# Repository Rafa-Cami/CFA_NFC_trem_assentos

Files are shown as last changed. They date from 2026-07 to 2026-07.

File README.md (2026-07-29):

<p align="center">
  <br/>
  <b>Prioriza: Sistema de sensores para assentos preferenciais</b><br/>
  <text>🚈 Relatório do projeto</text>
</p>

<br/>

## 📍Introdução

O projeto de cartões de identificação, desenvolvido na disciplina de [CFA](https://github.com/FNakano/CFA), tem como objetivo desenvolver um projeto utilizando a tecnologia de NFC para realizar avisos sonoros e alertar os passageiros do vagão. Para ver outros projetos relacionados que utilizam NFC, utilizamos como inspiração o projeto [CardForRPG](https://github.com/Felipe256/CardForRPG) e o projeto [SMAC - Sistema de Monitoramento para Assentos de Cadeira de Roda](https://github.com/Anemaygi/SMAC/tree/master/projeto) que apresenta uma possibilidade de implementação para os sensores de toque detectarem presença em um assento.

### 🗺️ Aplicação Real

A iniciativa foi inspirada no sistema de sensores utilizado no metrô da Coreia do Sul e seu aplicativo [pinklight](https://play.google.com/store/apps/details?id=kr.doweb.pinklight&hl=pt_BR), para criar uma solução baseada em IoT que incentive os passageiros a dar lugar à mulheres grávidas no assento preferencial. Segundo o [estudo de caso](https://publicadministration.un.org/unpsa/en/Home/Case-Details-Public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), "Recentemente, como muitos passageiros ficam absortos em seus smartphones enquanto viajam de ônibus ou metrô, é possível que raramente notem uma gestante por perto. Partindo do princípio de que muitos dos passageiros que não estão grávidos, mas ocupam assentos preferenciais, estariam de fato dispostos a ceder o lugar a uma mulher caso percebessem que ela está grávida, a cidade de Busan lançou o 'Pink Light'".

Assim, o dispositivo seria uma forma de alertar os passageiros quando devem ceder seu lugar para outro passageiro, sem necessidade de perguntar e sem que seja necessário pedir. É uma tecnologia relativamente barata de ser implementada como política pública que incentiva o bem-estar de diferentes grupos sociais com direito ao assento preferencial, como por exemplo: Pessoas com deficiência, pessoas com crianças de colo, idosos, obesos, gestantes, pessoas com restrição de mobilidade e autistas.

## 🗂️ Organização do repositório e primeiros passos:

## 👩‍🦯‍➡️ História de usuário (exemplificação de como funcionaria o projeto):

### usuário com direito ao assento preferencial

 1. ao entrar no trem o usuario deve ter em mãos o acessorio (cartão ou chaveiro) que tem informações sobre o assento preferencial
 2. o usuário deve encostar o acessório no dispositivo no sensor de nfc (requisito esse estar localizado com fácil acesso)
 3. o usuário verá a luz acima dos assentos liberados acender
     3.5 Se não houverem assentos livres, os passageiros ouviram o anuncio da chegada do passageiro preferencial e necessidade de liberação de assentos preferenciais
 4. o usuário pode ir até o assento, necessitando possivelmente que outros passageiros deem lugar sabendo da presença do passageiro preferencial

### usuários sem acesso ao assento preferencial

 1. ao chegar no trem, se houver um assento vazio e nao houver pessoas preferenciais usuário pode se sentar no assento preferencial
 2. o usuário fica tranquilo e quando chega na proxima estação se houver um usuario que deseja usar o assento preferencial ele ouve um anúncio
 3. o usuario deve se levantar, permitindo que a luz de assento livre ligue
 4. o usuario com direito ao assento verá o assento livre e se sentará nele

### preocupação com funcionalidade

- importante reforçar que a implementação do projeto envolve também a mudança no comportamento do usuário. Se implementado na vida real, o sucesso do projeto depende das pessoas cederem seus assentos. 

- O projeto em suas primeiras versões tem impedimentos para seu funcionamento em horários de pico. Os motivos são 
1. limitação no número de assentos
2. Possível lotação pode impedir o usuário de chegar ate o sensor do cartão. A lotação tambem pode impedir o usuário de enxergar a luz que sinaliza o assento livre, bem como impedir o deslocamento do usuario até lá.

## ⚙️ Como foi feito o projeto:

### 🔧 Componentes:
O projeto utiliza:
- 3 ESP32-C3 mini
- 1 PN532
- 1 Buzzer
- 4 Módulo sensor de toque capacitivo TTP223B
- 2 LED
- 2 Protoboard
- N Jumper
- PC ou outro dispositivo para atuar como servidor

**código em micropython e comunicação via TCP/IP com necessidade de os ESP32 e o Servidor se conectarem em mesma rede**

## 📖 Documentação do Código:

### Estrutura do Projeto:
O projeto está organizado em três blocos principais, cada um com uma função bem definida no funcionamento do sistema:

- Módulo de leitura NFC: localizado em 'esp_comunicando.py' e 'nfc_buzzer.py'. Esse módulo é responsável por interagir com o leitor PN532, ler o UID de cartões ou chaveiros NFC e identificar se o identificador corresponde a um usuário autorizado, além da comunicação com o servidor. Também há uma camada de inicialização em 'start.py', que chama o fluxo principal do leitor.

<p align="center">
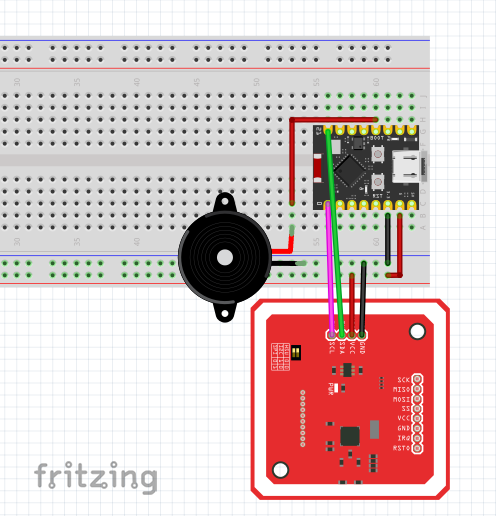
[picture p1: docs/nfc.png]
  <br/>
  <b>Esquema do Módulo de Leitor NFC</b><br/>
</p>

- Módulo de assentos: implementado em 'sensor_v1.py' e 'seat_state.py'. Aqui ficam os sensores de toque capacitivo, o LED de indicação e a lógica de estado do assento. O código decide se o assento está ocupado ou disponível e controla se o LED deve permanecer aceso ou apagado.

<p align="center">
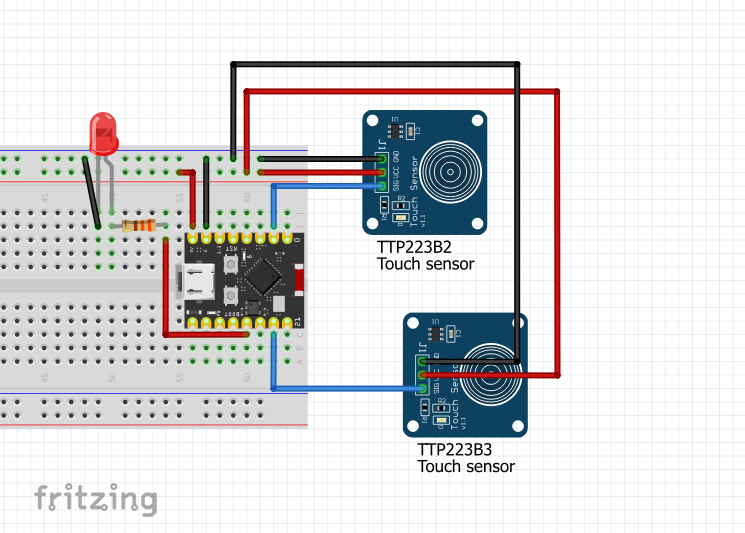
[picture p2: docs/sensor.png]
  <br/>
  <b>Esquema do Módulo de Assentos</b><br/>
</p>

- Servidor central: implementado em 'pc_server.py'. Esse componente funciona como cérebro do sistema. Ele recebe mensagens dos ESPs, mantém um registro dos assentos conectados, consulta o estado deles e decide qual assento deve receber o sinal de indicação após um evento NFC.

**A organização do repositório segue essa divisão: uma pasta para o ESP de NFC, outra para o ESP dos assentos e outra para o servidor. Além disso, há arquivos de configuração local, como esp_config.py, que definem Wi-Fi, IP do servidor e parâmetros específicos de cada dispositivo.**

### Responsabilidade de cada ESP32:
O projeto utiliza dois ESP32 com papéis distintos:

ESP32 do leitor NFC: é o dispositivo responsável por detectar a presença de um cartão ou chaveiro próximo ao leitor PN532. Quando um cartão é lido, ele verifica se o UID está na lista de identificadores autorizados. Se for um usuário válido, ele envia uma mensagem para o servidor informando que um evento NFC ocorreu. Também pode acionar um buzzer para fornecer feedback sonoro ao usuário.

ESP32 dos assentos: é o dispositivo ligado fisicamente ao assento. Ele monitora dois sensores de toque capacitivo para verificar se alguém está sentado.
Mantém um estado interno do assento, usando uma janela de leituras para evitar flutuações momentâneas. Controla um LED que indica visualmente se o assento está livre ou foi selecionado para um passageiro preferencial. Responde a comandos vindos do servidor, como consultar status do assento ou acender/apagar o LED.

OBS: nesse projeto foi utilizado 3 ESP32, 1 leitor NFC e 2 dos assentos.

### Fluxo de comunicação entre os dispositivos
A comunicação entre os dispositivos é feita via TCP/IP, usando mensagens em formato JSON. O fluxo principal funciona assim:

- Inicialização:
  - Cada ESP32 conecta-se à rede Wi-Fi configurada;
  - O ESP32 dos assentos se conecta ao servidor e envia um registro com seu identificador de assento;
  - O servidor armazena essa conexão e passa a considerar aquele assento disponível para futuras decisões;

- Leitura do NFC.
  - O ESP32 de NFC lê o UID do cartão aproximado ao leitor.
  - Se o UID estiver autorizado, ele envia uma mensagem ao servidor, indicando que um passageiro preferencial foi detectado.

- Decisão do servidor
  - O servidor recebe a mensagem do NFC e procura entre os assentos registrados aquele que está disponível.
  - Para isso, ele consulta cada assento e verifica se ele está livre.
Quando encontra um assento adequado, envia um comando para acender o LED desse assento.

- Atualização do estado do assento
  - O ESP32 do assento recebe o comando e atualiza seu estado interno.
  - Enquanto a pessoa permanece sentada, os sensores capacitivos continuam detectando ocupação e o LED é desligado quando o assento passa a ser considerado ocupado.
  - O servidor pode então continuar a acompanhar o estado do assento por meio das respostas recebidas.

- Feedback e reutilização
  - O sistema fica preparado para novos eventos: quando um novo usuário NFC chega, o servidor repete o processo e tenta ativar outro assento disponível.

Esse fluxo torna o projeto escalável e modular: o leitor NFC não precisa conhecer diretamente a lógica dos assentos; ele apenas notifica o servidor, e o servidor coordena a decisão com base no estado de todos os assentos conectados.

**Esquema de mensagens:**

| **Mensagem** | **Fluxo** | **Função** |
| --- | --- | --- |
| `seat_register`  | ESP Assento → Servidor | Registrar assento |
| `get_status` | Servidor → ESP Assento | Consultar estado |
| `seat_status` | ESP Assento → Servidor | Informar estado |
| `set_led` | Servidor → ESP Assento | Controlar LED |
| `set_led_result` | ESP Assento → Servidor | Confirmar comando |
| `nfc_*` | ESP NFC → Servidor | Informar leitura NFC |

### Bibliotecas Utilizadas

- Machine: usada em código para MicroPython no ESP32. Ela permite acessar recursos de hardware diretamente, como:
  - pinos digitais (Pin);
  - comunicação I2C (I2C);
  - PWM (PWM).
No projeto, ela é essencial para:
  - configurar o leitor NFC PN532;
  - controlar o buzzer;
  - ler os sensores de toque e acionar o LED.

- Network: é usada para gerenciar a conexão Wi-Fi no ESP32. Com ela, o dispositivo:
  - ativa a interface Wi-Fi;
  - conecta-se à rede;
  - verifica se está conectado.
No projeto, ela é usada para permitir que os ESP32 se comuniquem com o servidor via rede.

- Socket: é usada para criar conexões de rede TCP/IP. Ela permite que:
  - o ESP32 abra uma conexão com o servidor;
  - o servidor aceite conexões de múltiplos dispositivos;
  - as mensagens JSON sejam transmitidas entre os módulos.
No projeto, ela é usada principalmente no servidor e também no ESP32 para enviar e receber dados.

- Uasyncio: permite escrever código que executa tarefas simultaneamente, como no projeto, que ela é importante no ESP32 dos assentos porque o código precisa lidar com várias operações ao mesmo tempo.

- Json: usada para serializar e desserializar mensagens no formato JSON. Isso é importante porque nosso sistema troca dados estruturados. Ela transforma dicionários Python em texto e vice-versa.

- Time: usada para controle temporal.

- Micropython.const: usada para definir constantes de forma eficiente no MicroPython. Ela ajuda a criar valores simbólicos para comandos do PN532 e outras configurações fixas.

- Threading: usada no servidor para lidar com várias conexões simultaneamente. Com ela, o servidor consegue:
  - atender múltiplos clientes ao mesmo tempo;
  - processar mensagens de diferentes dispositivos;
  - manter a comunicação sem bloquear o fluxo principal.

### Outros recursos de software utilizados
Além da lógica principal de leitura NFC, controle de assentos e comunicação com o servidor, o sistema também faz uso de alguns recursos de software que aumentam sua robustez, organização e facilidade de manutenção.

Primeiramente, o projeto utiliza mecanismos de gerenciamento de estado para representar o comportamento de cada assento. Isso permite controlar se o assento está ocupado ou disponível, se o LED deve permanecer aceso e se uma solicitação de ativação foi aceita ou rejeitada. Esse controle é essencial para evitar inconsistências durante a execução.

Também foi empregado um modelo de programação assíncrona no ESP32 de assentos, por meio de uasyncio, o que permite que o dispositivo monitore os sensores, mantenha a conexão com o servidor e responda a comandos sem travar o sistema. Essa abordagem é importante porque o hardware embarcado precisa lidar com múltiplas tarefas ao mesmo tempo.

No servidor, o projeto utiliza concorrência com threading, além de mecanismos de bloqueio, para atender várias conexões simultaneamente. Isso é especialmente útil quando há mais de um dispositivo conectado ao mesmo tempo, como vários ESP32 de assentos ou eventos de NFC ocorrendo em sequência.

Outro recurso relevante é o tratamento de erros e reconexão. O sistema é preparado para lidar com falhas de rede, desconexões temporárias e respostas inesperadas, tentando restabelecer a comunicação automaticamente sempre que possível. Isso aumenta a confiabilidade do funcionamento em ambiente real.

O projeto também depende de arquivos de configuração específicos para cada dispositivo, como dados de rede Wi-Fi, endereço do servidor e identificadores de assento. Essa separação facilita a adaptação do sistema para diferentes ambientes sem alterar o código principal.

Por fim, o repositório conta com testes automatizados, que verificam o comportamento do servidor em cenários como registro de assentos, controle de timeout, ativação de LED e tratamento de mensagens inválidas. Esses testes ajudam a garantir que as mudanças no software não comprometam o funcionamento do sistema.

## 📢 Futuras Implementações:

- Interação de múltiplos módulos de leitor de NFC com um só servidor no vagão
- Mensagem mais amigável por meio de um alto falante (integrado ou não com o sistema de som do trem)
- Diferentes meios de detecção do NFC (Cartões, chaveiros, colares)
- Detecção avançada, por meio de sensores com maior alcance nas portas, assim não precisando de contato direto com o leitor]
- Confirmação visual de deteção no meio (luz piscando, vibração, etc)
- Sistema de controle para detectar se uma pessoa sentada no assento preferencial de fato necessita dele ou não (por meio de detecção no assento)

## 🔍 Como visualizar o site com nosso pitch?

- Clone o repositório localmente;
- Instale a extensão "Live Server";
- No documento landing_page/index.html, com o botão direito, clique em "Open with Live Server";
- Prontinho, nosso site será aberto em seu navegador padrão!

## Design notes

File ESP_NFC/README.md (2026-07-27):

# NFC, sensores de assento e buzzer

Módulo do Projeto em MicroPython para ESP32-C3 SuperMini com PN532 em I2C.
O firmware de producao (`esp_comunicando.py`, gravado como `main.py`) le o
cartao NFC, envia o evento ao servidor do PC via TCP e aciona o buzzer
conforme a resposta (sucesso, sem assento livre ou cartao nao autorizado).
Existe tambem um teste isolado de bancada (`start.py` + `nfc_buzzer.py`) que
apenas imprime o UID no REPL e apita — **esse teste nao tem rede e nao fala
com o servidor**.

## Hardware

Ligacoes usadas pela montagem atual:

| Componente | Pino | ESP32-C3 |
| --- | --- | --- |
| PN532 | SDA | GPIO8 |
| PN532 | SCL | GPIO9 |
| PN532 | VCC | 3V3 |
| PN532 | GND | GND |
| Buzzer passivo | + | GPIO4 |
| Buzzer passivo | - | GND |

O PN532 deve estar configurado para I2C e responder no endereco `0x24`.

Ligacoes usadas no ESP32-C3 dos assentos:

| Componente | ESP32-C3 | Estado ocupado |
| --- | --- | --- |
| Sensor capacitivo 1 | GPIO10 | nivel alto (`1`) |
| Sensor capacitivo 2 | GPIO7 | nivel alto (`1`) |
| Resistor para LED| - | - |
| LED do assento | GPIO5 | - |

Os dois sensores formam um unico estado agregado e sao lidos a cada 500 ms.
Se qualquer sensor indicar ocupacao, o assento permanece ocupado por 5 segundos
contados a partir da leitura ocupada mais recente. Uma nova deteccao em qualquer
sensor reinicia essa janela. Sem deteccoes nos ultimos 5 segundos, inclusive
logo depois da inicializacao, o assento fica disponivel.

## Estrutura Do Codigo

O projeto agora fica separado por modulo, cada um com sua propria pasta `src`:

- `servidor/src/`: codigo do PC/servidor TCP.
- `ESP_NFC/src/`: codigo do ESP32 com leitor NFC PN532.
- `ESP_Assentos/src/`: codigo do ESP32 que controla sensor/LED do assento.

O ESP dos assentos continua sendo cliente TCP: ele abre e mantem uma conexao
com o servidor do PC. Ao conectar, envia um registro com seu `SEAT_ID` e depois
um heartbeat a cada 500 ms com o estado agregado. O servidor deixa de selecionar
um assento se nao receber heartbeat por 1,5 segundo. Quando recebe um NFC, usa o
estado recente armazenado e solicita o acionamento do LED ao primeiro assento
disponivel.

## Protocolo Do Assento

As mensagens continuam sendo JSON delimitado por quebra de linha:

```text
ESP -> PC: {"type":"seat_register","seat_id":"seat_1"}
ESP -> PC: {"type":"seat_heartbeat","seat_id":"seat_1","status":"disponível","led":0}
PC  -> ESP: {"type":"set_led","request_id":17,"value":1}
ESP -> PC: {"type":"set_led_result","request_id":17,"accepted":true}
```

O `request_id` permite ao servidor associar a resposta ao comando correto.
O ESP recusa `set_led` quando o assento esta ocupado ou quando o LED ja esta
aceso.

## Arquivos Embarcados

Para o ESP32 com NFC, copie `ESP_NFC/src/esp_config.example.py` para
`ESP_NFC/src/esp_config.py` e ajuste `SSID`, `PASSWORD` e `HOST`. Esse arquivo
contem configuracoes locais e e ignorado pelo Git. Ajuste `NFC_UUIDS` em
`esp_comunicando.py` quando necessario.

No Thonny, salve `esp_config.py` na raiz do dispositivo com o mesmo nome e
salve `esp_comunicando.py` como `main.py`.

Somente para testar o leitor NFC com buzzer de forma isolada (sem rede),
copie estes arquivos de `ESP_NFC/src` para a raiz do filesystem MicroPython:

- `start.py`
- `nfc_buzzer.py`

Nao use esse modo no MVP integrado: `nfc_buzzer.py` nao se conecta ao Wi-Fi
nem ao servidor.

Para o ESP32 dos assentos, copie `ESP_Assentos/src/esp_config.example.py` para
`ESP_Assentos/src/esp_config.py` e ajuste a rede, o IP do servidor e `SEAT_ID`.
Salve `esp_config.py` e `seat_state.py` na raiz do dispositivo e salve
`sensor_v1.py` como `main.py`. Cada ESP de assento deve usar um `SEAT_ID`
diferente.

Ao receber um NFC autorizado, o servidor consulta os assentos registrados em
ordem de `SEAT_ID`. O primeiro ESP que responder disponivel e aceitar o comando
tera o LED aceso. O LED apaga localmente assim que a janela agregada detectar
ocupacao.

## Uso

O firmware de producao roda sozinho ao ligar a placa: `esp_comunicando.py`
gravado como `main.py` conecta no Wi-Fi, abre a conexao TCP com o servidor e
fica aguardando cartoes. Basta iniciar o servidor no PC e energizar o ESP32.

Saida esperada na inicializacao (visivel em um monitor serial):

```text
Starting NFC + TCP/IP
I2C: SDA=GPIO8, SCL=GPIO9
Buzzer: GPIO4
Connected to Wi-Fi
ESP32 IP: 192.168.x.x
I2C devices: ['0x24']
Found PN532 firmware version: 1.6
Waiting for NFC card...
Connecting to PC 192.168.x.x:5000...
Connected to PC
```

Ao aproximar um cartao autorizado:

```text
Found card UID: d3:8e:18:06
Sent: {'nfc_1': 1}
PC response: {'status': 'ok', ...}
```

**Atencao (Thonny):** ao conectar o Thonny na porta serial da placa, ele
interrompe o `main.py` em execucao e deixa o ESP parado no REPL — o NFC para
de se comunicar com o servidor. Durante a operacao do MVP, mantenha o Thonny
fechado/desconectado. Para voltar a operar apos usar o Thonny, desconecte-o e
reinicie a placa (botao reset ou `python -m mpremote connect COM3 reset`).

### Teste isolado (bancada, sem rede)

Com `start.py` e `nfc_buzzer.py` gravados, execute no REPL do Thonny:

```python
import start
```

Saida esperada: `Starting NFC buzzer test` e o UID dos cartoes aproximados.
Para parar o loop no Thonny, use `Ctrl+C` ou `Ctrl+F2`.

## Upload Com mpremote

Feche ou desconecte o backend do Thonny antes de usar `mpremote`, pois a porta
serial nao pode ser usada por dois programas ao mesmo tempo.

```powershell
python -m mpremote connect COM3 fs cp .\ESP_NFC\src\esp_config.py :esp_config.py
python -m mpremote connect COM3 fs cp .\ESP_NFC\src\esp_comunicando.py :main.py
python -m mpremote connect COM4 fs cp .\ESP_Assentos\src\esp_config.py :esp_config.py
python -m mpremote connect COM4 fs cp .\ESP_Assentos\src\seat_state.py :seat_state.py
python -m mpremote connect COM4 fs cp .\ESP_Assentos\src\sensor_v1.py :main.py
```

## Servidor No PC

Antes de ligar o ESP32 NFC, rode o servidor:

```powershell
python servidor\src\pc_server.py
```

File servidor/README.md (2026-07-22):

# Para implementar o projeto: 

Nessa pasta encontra-se o código para rodar o servidor necessário para fazer a comunicação entre os ESP32

Antes de ligar o ESP32 NFC, rode o servidor:

```powershell
python pc_server.py
```
ou (se estiver na pasta principal do repositório):

```powershell
python servidor\src\pc_server.py
```

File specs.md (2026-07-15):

# NFC Buzzer

Projeto MicroPython para ESP32-C3 SuperMini com PN532 em I2C. Ao aproximar um
cartao NFC do modulo PN532, o ESP32 imprime o UID no REPL e aciona um buzzer
passivo conectado ao GPIO4.

## Hardware

Ligacoes usadas pela montagem atual:

| Componente | Pino | ESP32-C3 |
| --- | --- | --- |
| PN532 | SDA | GPIO8 |
| PN532 | SCL | GPIO9 |
| PN532 | VCC | 3V3 |
| PN532 | GND | GND |
| Buzzer passivo | + | GPIO4 |
| Buzzer passivo | - | GND |

O PN532 deve estar configurado para I2C e responder no endereco `0x24`.

## Estrutura Do Codigo

O projeto agora fica separado por modulo, cada um com sua propria pasta `src`:

- `servidor/src/`: codigo do PC/servidor TCP.
- `ESP_NFC/src/`: codigo do ESP32 com leitor NFC PN532.
- `ESP_Assentos/src/`: codigo do ESP32 que controla sensor/LED do assento.

## Arquivos Embarcados

Para o ESP32 com NFC, copie `ESP_NFC/src/esp_config.example.py` para
`ESP_NFC/src/esp_config.py` e ajuste `SSID`, `PASSWORD` e `HOST`. Esse arquivo
contem configuracoes locais e e ignorado pelo Git. Ajuste `NFC_UUIDS` em
`esp_comunicando.py` quando necessario.

No Thonny, salve `esp_config.py` na raiz do dispositivo com o mesmo nome e
salve `esp_comunicando.py` como `main.py`.

Para testar apenas o leitor NFC com buzzer, copie estes arquivos de
`ESP_NFC/src` para a raiz do filesystem MicroPython:

- `start.py`
- `nfc_buzzer.py`

Para o ESP32 dos assentos, copie `ESP_Assentos/src/esp_config.example.py` para
`ESP_Assentos/src/esp_config.py` e ajuste a rede, o IP do servidor e `SEAT_ID`.
Salve `esp_config.py` na raiz do dispositivo e salve `sensor_v1.py` como
`main.py`. Cada ESP de assento deve usar um `SEAT_ID` diferente.

O assento informa ao servidor quando o sensor esta inativo. Ao receber um NFC
autorizado, o servidor seleciona o primeiro assento livre e manda acender o
LED. O LED apaga quando o sensor detecta que alguem se sentou.

## Uso

No Thonny, conecte ao ESP32 e execute no REPL:

```python
import start
```

Saida esperada na inicializacao:

```text
Starting NFC buzzer test
I2C: SDA=GPIO8, SCL=GPIO9
Buzzer: GPIO4
I2C devices: ['0x24']
Found PN532 firmware version: 1.6
Waiting for NFC card...
```

Ao aproximar um cartao:

```text
Found card UID: d3:8e:18:06
```

Para parar o loop no Thonny, use `Ctrl+C` ou `Ctrl+F2`.

## Upload Com mpremote

Feche ou desconecte o backend do Thonny antes de usar `mpremote`, pois a porta
serial nao pode ser usada por dois programas ao mesmo tempo.

```powershell
python -m mpremote connect COM3 fs cp .\ESP_NFC\src\esp_config.py :esp_config.py
python -m mpremote connect COM3 fs cp .\ESP_NFC\src\esp_comunicando.py :main.py
python -m mpremote connect COM4 fs cp .\ESP_Assentos\src\esp_config.py :esp_config.py
python -m mpremote connect COM4 fs cp .\ESP_Assentos\src\sensor_v1.py :main.py
```

## Servidor No PC

Antes de ligar o ESP32 NFC, rode o servidor:

```powershell
python servidor\src\pc_server.py
```

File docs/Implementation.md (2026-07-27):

# Como reproduzir o projeto

## Componentes Estruturais

Para estruturar fisicamente o projeto, serão realizados 3 protótipos, dividos em 3 partes (módulo de leitura do Cartão NFC, o PC intermediário que servirá como Hotspot e o módulo dos assentos)

### Componentes Estruturais do primeiro protótipo

#### Módulo de leitura NFC: 

| Quantidade | Componente |
| --- | --- |
| 1 | OLED ESP32 C3 |
| 1 | Leitor NFC  PN532 |
| 1 | Buzzer |
| 1 | Protoboard |
| N (valor variável) | Jumpers |

#### PC Intermediário Hotspot
- Um PC configurado como hotspot de conexão entre o módulo de leitura NFC e o módulo dos assentos

#### Módulo dos assentos:

| Quantidade | Componente |
| --- | --- |
| 1 | OLED ESP32 C3 |
| 1 | LED |
| 2 | Módulo sensor de toque capacitivo TTP223B |
| 1 | Protoboard |
| N (valor variável)| Jumpers |

### Componentes Estruturais adicionais do segundo protótipo

Para o segundo protótipo, integraremos mais um módulo de assentos, portanto adicionaremos:

| Quantidade | Componente |
| --- | --- |
| 1 | OLED ESP32 C3 |
| 1 | LED |
| 2 | Módulo sensor de toque capacitivo TTP223B |
| 1 | Protoboard |
|  N (valor variável) | Jumpers |

# Como implementar/rodar:
## NFC Buzzer

Modulo do projeto que utiliza MicroPython para ESP32-C3 SuperMini com PN532 em I2C. Ao aproximar um
cartao NFC do modulo PN532, o ESP32 imprime o UID no REPL e aciona um buzzer
passivo conectado ao GPIO4.

### Hardware

Ligacoes usadas pela montagem atual:

| Componente | Pino | ESP32-C3 |
| --- | --- | --- |
| PN532 | SDA | GPIO8 |
| PN532 | SCL | GPIO9 |
| PN532 | VCC | 3V3 |
| PN532 | GND | GND |
| Buzzer passivo | + | GPIO4 |
| Buzzer passivo | - | GND |

O PN532 deve estar configurado para I2C e responder no endereco `0x24`.

### Estrutura Do Codigo

O projeto agora fica separado por modulo, cada um com sua propria pasta `src`:

- `servidor/src/`: codigo do PC/servidor TCP.
- `ESP_NFC/src/`: codigo do ESP32 com leitor NFC PN532.
- `ESP_Assentos/src/`: codigo do ESP32 que controla sensor/LED do assento.

### Arquivos Embarcados

Para o ESP32 com NFC, copie `ESP_NFC/src/esp_config.example.py` para
`ESP_NFC/src/esp_config.py` e ajuste `SSID`, `PASSWORD` e `HOST`. Esse arquivo
contem configuracoes locais e e ignorado pelo Git. Ajuste `NFC_UUIDS` em
`esp_comunicando.py` quando necessario.

No Thonny, salve `esp_config.py` na raiz do dispositivo com o mesmo nome e
salve `esp_comunicando.py` como `main.py`.

Para testar apenas o leitor NFC com buzzer, copie estes arquivos de
`ESP_NFC/src` para a raiz do filesystem MicroPython:

- `start.py`
- `nfc_buzzer.py`

Para o ESP32 dos assentos, copie `ESP_Assentos/src/esp_config.example.py` para
`ESP_Assentos/src/esp_config.py` e ajuste a rede, o IP do servidor e `SEAT_ID`.
Salve `esp_config.py` na raiz do dispositivo e salve `sensor_v1.py` como
`main.py`. Cada ESP de assento deve usar um `SEAT_ID` diferente.

O assento informa ao servidor quando o sensor esta inativo. Ao receber um NFC
autorizado, o servidor seleciona o primeiro assento livre e manda acender o
LED. O LED apaga quando o sensor detecta que alguem se sentou.

### Uso

No Thonny, conecte ao ESP32 e execute no REPL:

```python
import start
```

Saida esperada na inicializacao:

```text
Starting NFC buzzer test
I2C: SDA=GPIO8, SCL=GPIO9
Buzzer: GPIO4
I2C devices: ['0x24']
Found PN532 firmware version: 1.6
Waiting for NFC card...
```

Ao aproximar um cartao:

```text
Found card UID: d3:8e:18:06
```

Para parar o loop no Thonny, use `Ctrl+C` ou `Ctrl+F2`.

### Upload Com mpremote

Feche ou desconecte o backend do Thonny antes de usar `mpremote`, pois a porta
serial nao pode ser usada por dois programas ao mesmo tempo.

```powershell
python -m mpremote connect COM3 fs cp .\ESP_NFC\src\esp_config.py :esp_config.py
python -m mpremote connect COM3 fs cp .\ESP_NFC\src\esp_comunicando.py :main.py
python -m mpremote connect COM4 fs cp .\ESP_Assentos\src\esp_config.py :esp_config.py
python -m mpremote connect COM4 fs cp .\ESP_Assentos\src\sensor_v1.py :main.py
```

## Servidor No PC

Antes de ligar o ESP32 NFC, rode o servidor:

```powershell
python servidor\src\pc_server.py
```

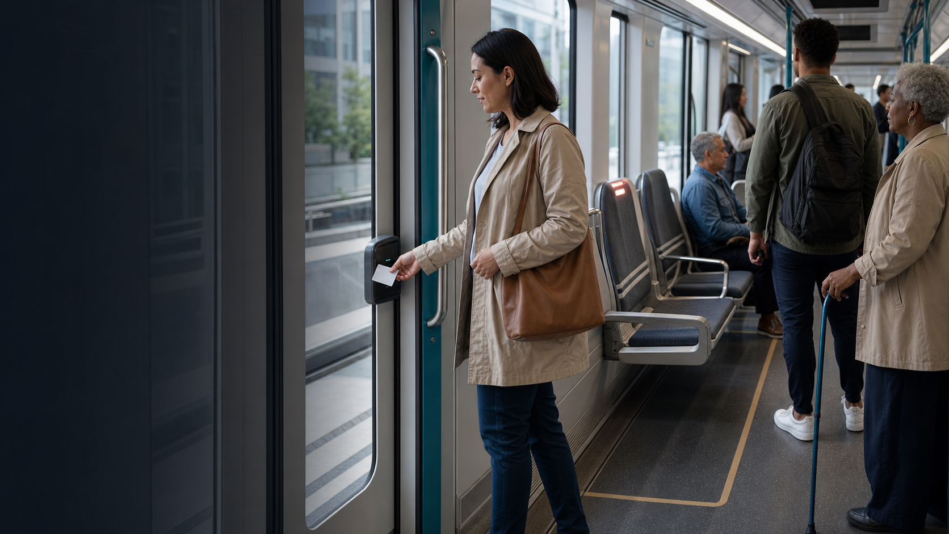
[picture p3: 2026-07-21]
landing page/assets/hero-prioriza.png

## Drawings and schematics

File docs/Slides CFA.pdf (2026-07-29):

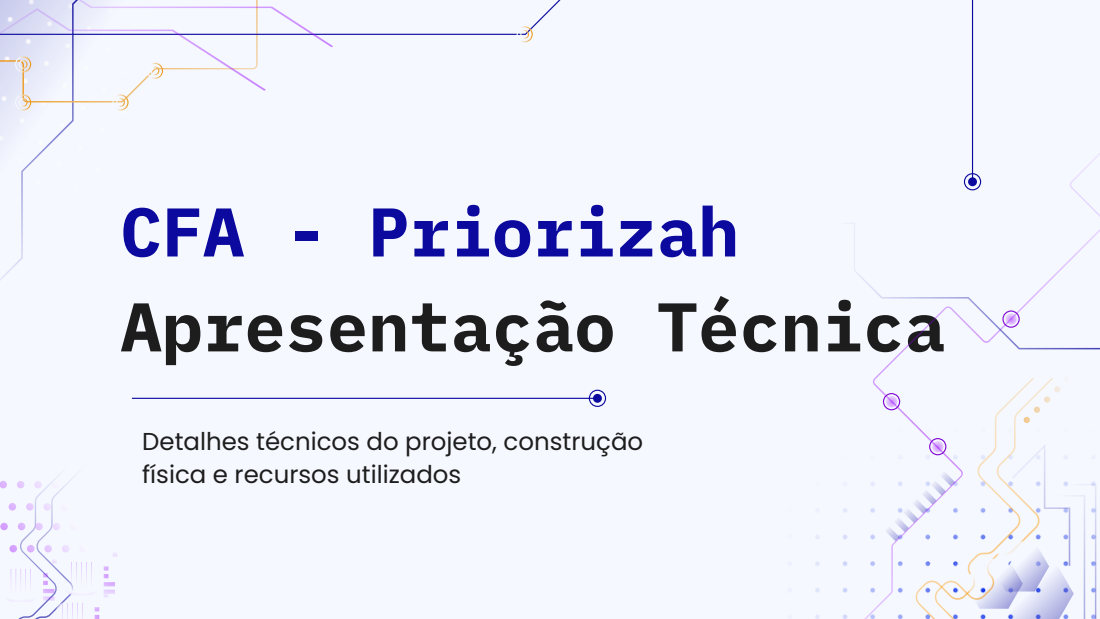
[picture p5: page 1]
CFA - Priorizah Apresentação Técnica

Detalhes técnicos do projeto, construção
física e recursos utilizados

# Índice

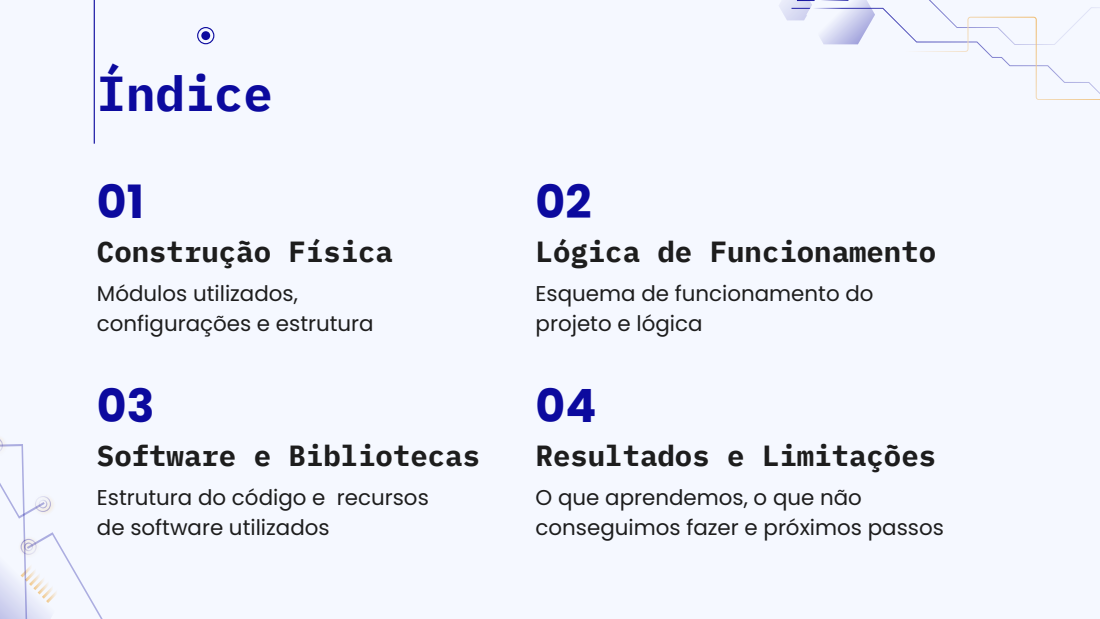
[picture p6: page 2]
Software e Bibliotecas; Resultados e Limitações

Construção Física
Módulos utilizados,
configurações e estrutura
Estrutura do código e recursos
de software utilizados

Lógica de Funcionamento
Esquema de funcionamento do
projeto e lógica

O que aprendemos, o que não
conseguimos fazer e próximos passos

01

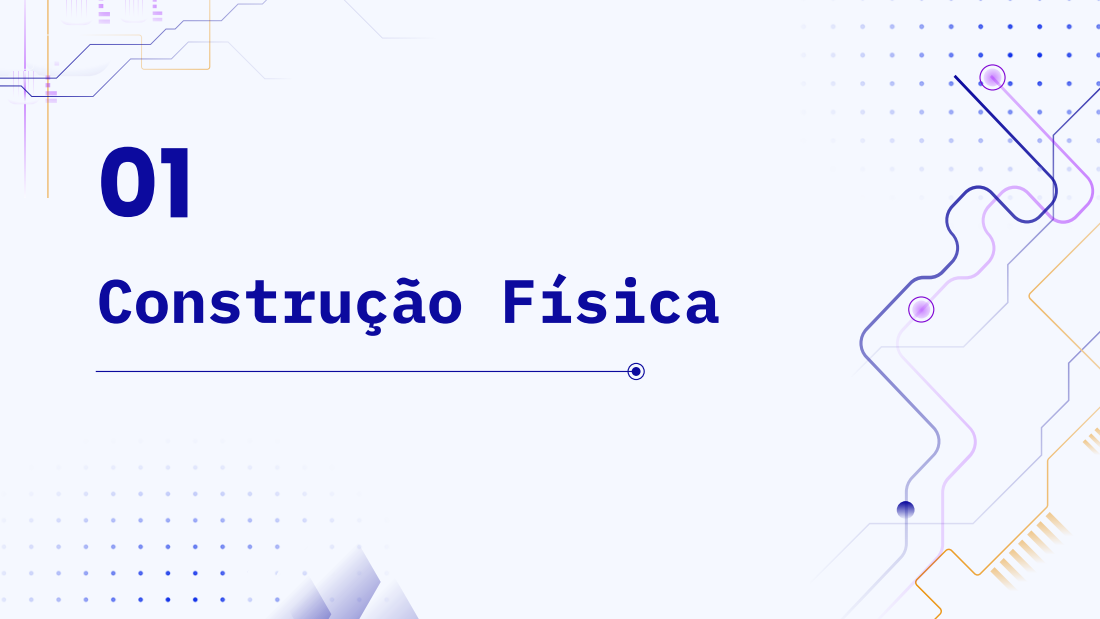
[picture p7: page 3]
Construção Física

# 1.1. Módulos Utilizados

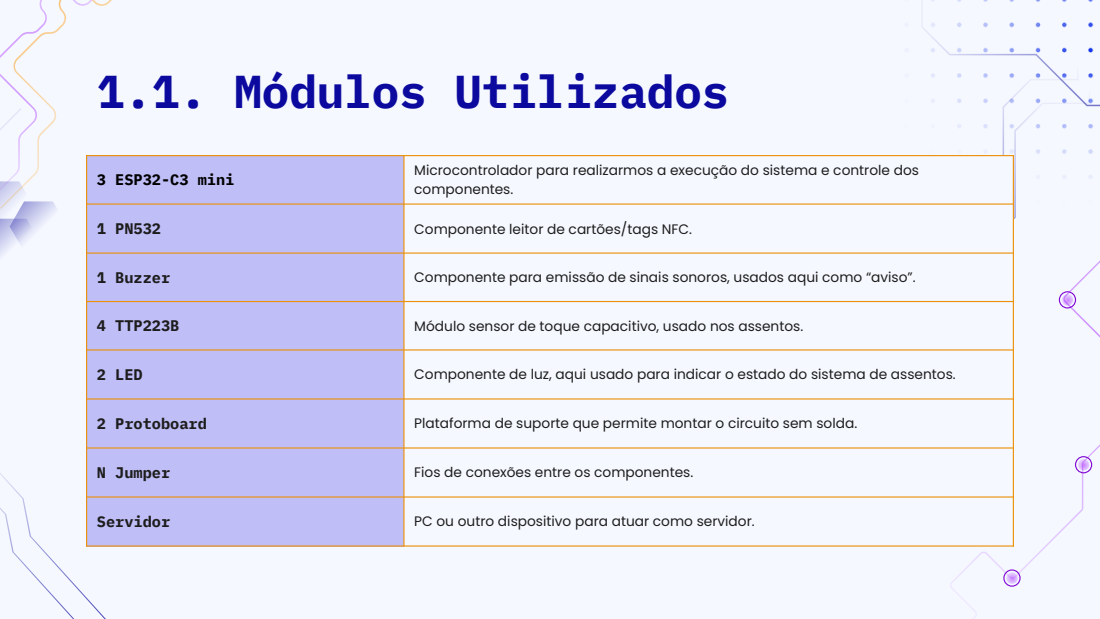
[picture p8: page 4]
3 ESP32-C3 mini; Microcontrolador para realizarmos a execução do sistema e controle dos

componentes.

1 PN532 | Componente leitor de cartões/tags NFC.

1 Buzzer | Componente para emissão de sinais sonoros, usados aqui como “aviso”.

4 TTP223B | Módulo sensor de toque capacitivo, usado nos assentos.

2 LED | Componente de luz, aqui usado para indicar o estado do sistema de assentos.

2 Protoboard | Plataforma de suporte que permite montar o circuito sem solda.

N Jumper | Fios de conexões entre os componentes.

Servidor | PC ou outro dispositivo para atuar como servidor.

# 1.2. Estrutura do projeto

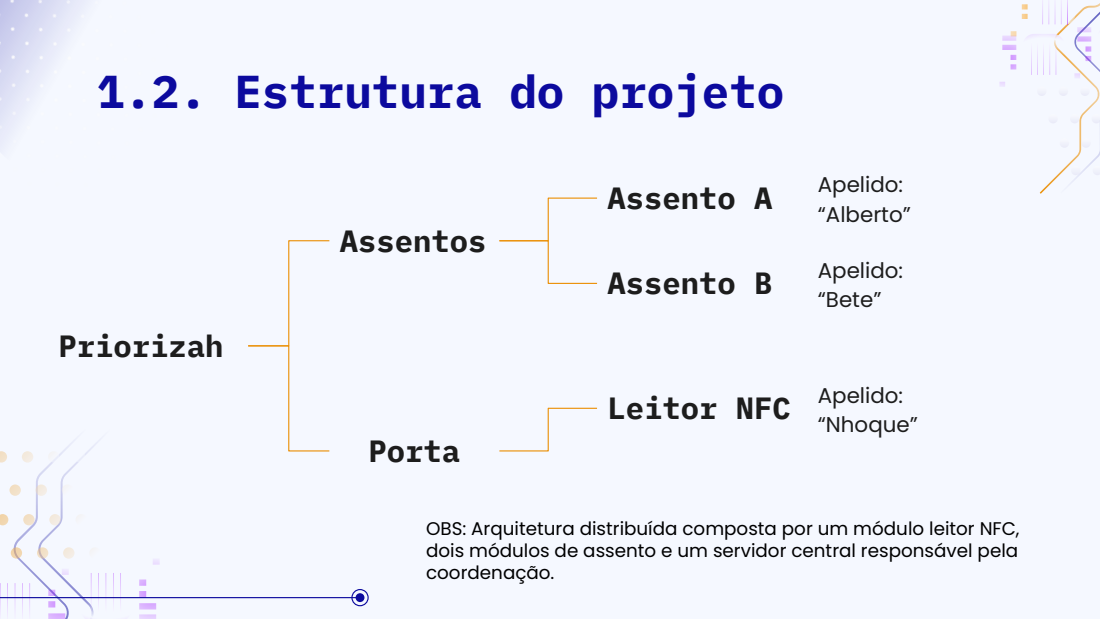
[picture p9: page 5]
Priorizah; Assentos; Apelido: “Alberto” Assento A; Apelido: “Bete” Assento B; Porta; Apelido:

“Nhoque” Leitor NFC

OBS: Arquitetura distribuída composta por um módulo leitor NFC,
dois módulos de assento e um servidor central responsável pela
coordenação.

# 1.2.1. “Alberto” e “Bete”

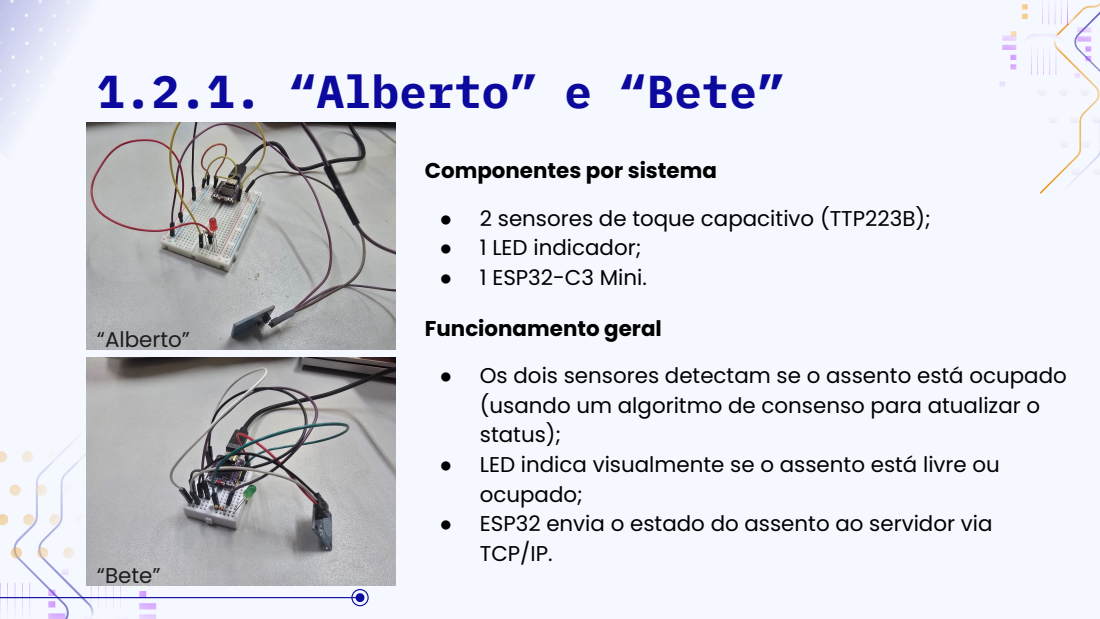
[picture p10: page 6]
“Alberto”; “Bete”

Componentes por sistema
● 2 sensores de toque capacitivo (TTP223B);
● 1 LED indicador;
● 1 ESP32-C3 Mini.
Funcionamento geral
● Os dois sensores detectam se o assento está ocupado
(usando um algoritmo de consenso para atualizar o
status);
● LED indica visualmente se o assento está livre ou
ocupado;
● ESP32 envia o estado do assento ao servidor via
TCP/IP.

# 1.2.2. “Nhoque”

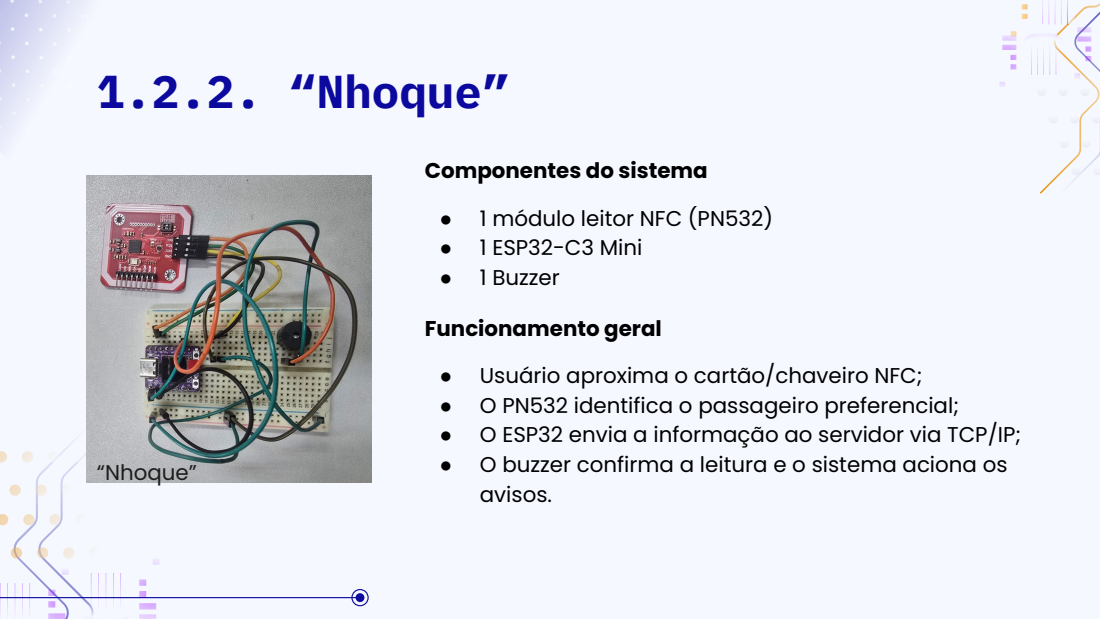
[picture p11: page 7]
“Bete” “Nhoque”

Componentes do sistema
● 1 módulo leitor NFC (PN532)
● 1 ESP32-C3 Mini
● 1 Buzzer
Funcionamento geral
● Usuário aproxima o cartão/chaveiro NFC;
● O PN532 identifica o passageiro preferencial;
● O ESP32 envia a informação ao servidor via TCP/IP;
● O buzzer confirma a leitura e o sistema aciona os
avisos.

02

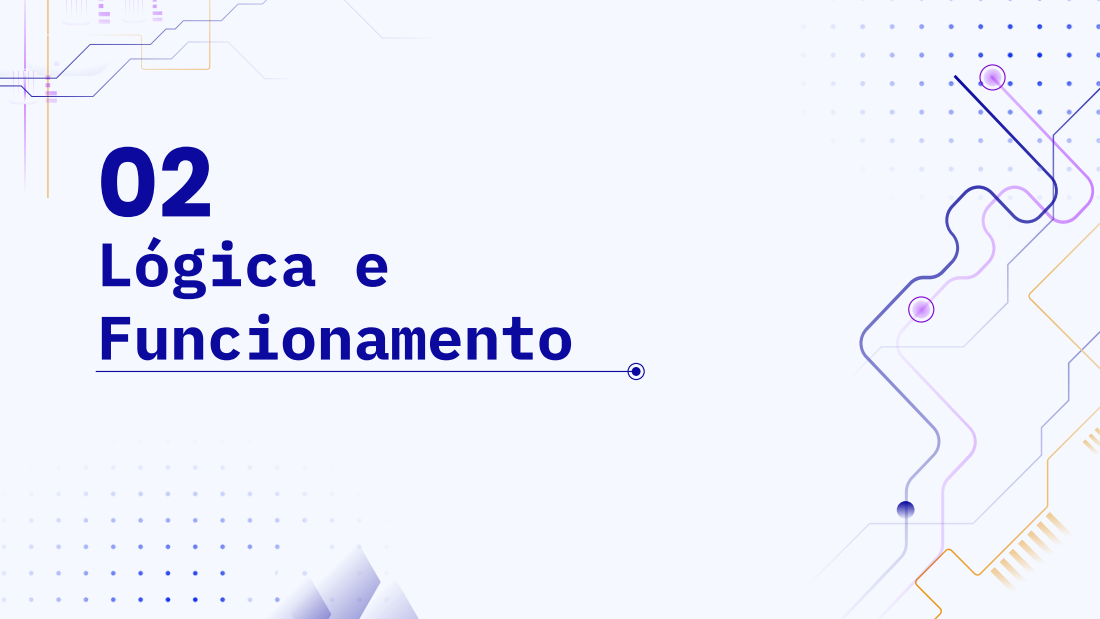
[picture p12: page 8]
Lógica e Funcionamento

# 2.1. Lógica de Ativação

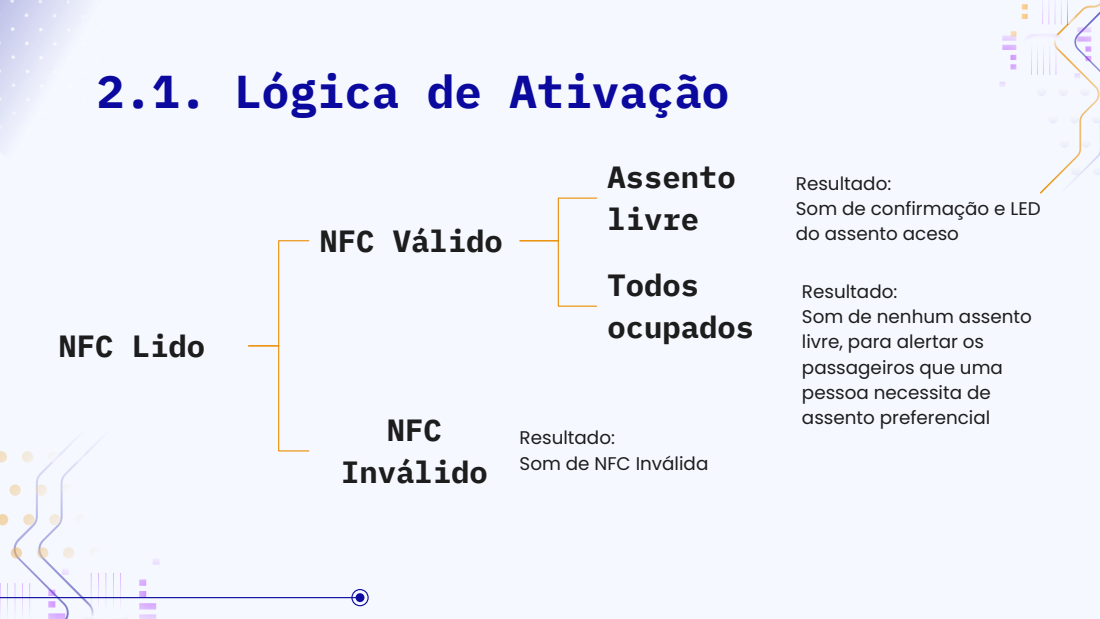
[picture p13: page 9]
NFC Lido; NFC Válido; Assento livre; Todos ocupados; NFC Inválido

Resultado:
Som de confirmação e LED
do assento aceso

Som de nenhum assento
livre, para alertar os
passageiros que uma
pessoa necessita de
assento preferencial

Som de NFC Inválida

# 2.2. Ordem de eventos

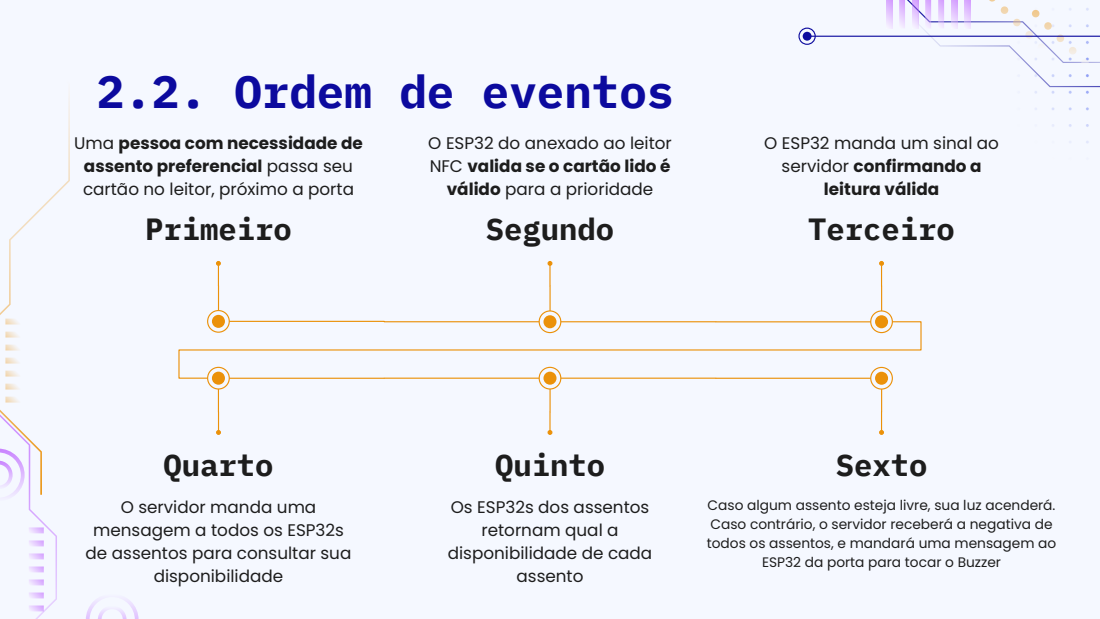
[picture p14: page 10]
Primeiro; Segundo; Terceiro; Quarto; Quinto; Sexto

Uma pessoa com necessidade de
assento preferencial passa seu
cartão no leitor, próximo a porta

O ESP32 do anexado ao leitor
NFC valida se o cartão lido é
válido para a prioridade

O ESP32 manda um sinal ao
servidor confirmando a
leitura válida

O servidor manda uma
mensagem a todos os ESP32s
de assentos para consultar sua
disponibilidade

Os ESP32s dos assentos
retornam qual a
disponibilidade de cada
assento

Caso algum assento esteja livre, sua luz acenderá.
Caso contrário, o servidor receberá a negativa de
todos os assentos, e mandará uma mensagem ao
ESP32 da porta para tocar o Buzzer

# 2.3. Lógica de Ocupação dos Assentos

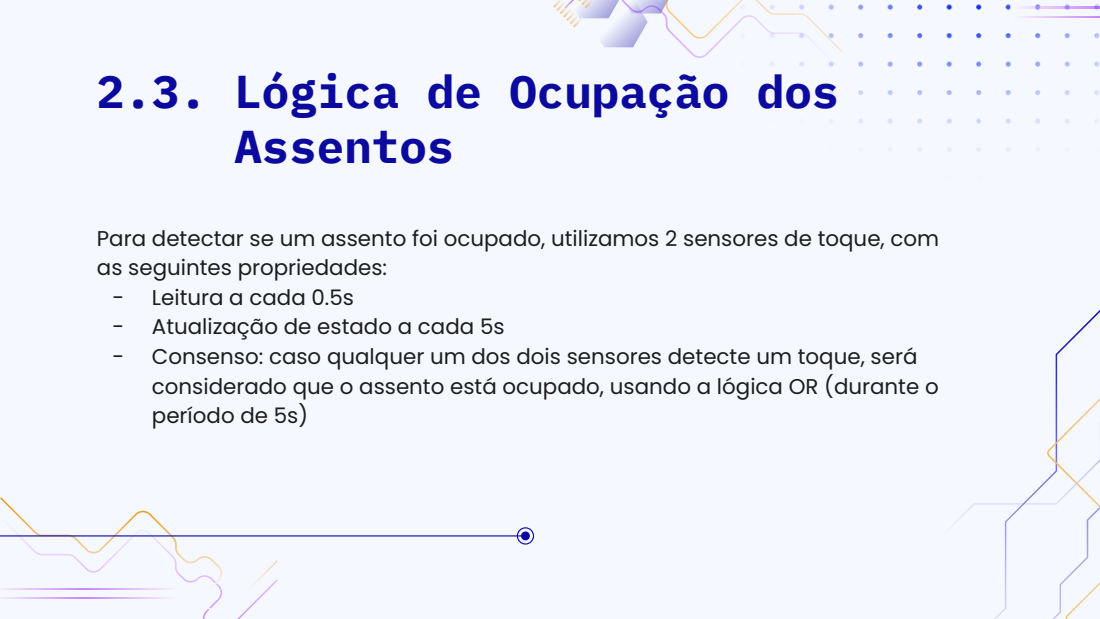
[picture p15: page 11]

Para detectar se um assento foi ocupado, utilizamos 2 sensores de toque, com
as seguintes propriedades:
- Leitura a cada 0.5s
- Atualização de estado a cada 5s
- Consenso: caso qualquer um dos dois sensores detecte um toque, será
considerado que o assento está ocupado, usando a lógica OR (durante o
período de 5s)

# Exemplo:

## Sensor 1

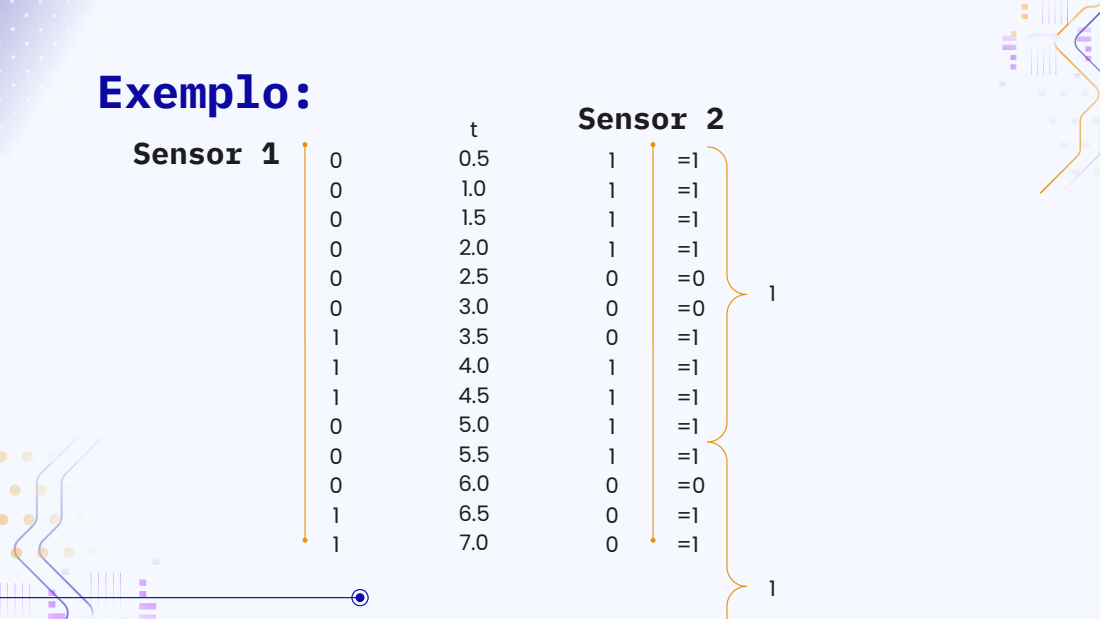
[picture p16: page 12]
Sensor 2

03

Software e Bibliotecas
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

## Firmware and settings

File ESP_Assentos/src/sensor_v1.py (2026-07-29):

import json
import time

import network
import uasyncio as asyncio
from machine import Pin

from seat_state import (
    LED_ACTIVATED,
    LED_ALREADY_ACTIVE,
    LED_DEACTIVATED,
    SeatState,
)

try:
    from esp_config import HOST, PASSWORD, SEAT_ID, SSID
except ImportError:
    raise RuntimeError(
        "Missing esp_config.py. Copy esp_config.example.py and configure it."
    )


PORT = 5000
SENSOR_1_PIN = 10
SENSOR_2_PIN = 7
LED_PIN = 5
AVAILABLE_SENSOR_VALUE = 0
SENSOR_INTERVAL_MS = 500
WINDOW_SIZE = 10
RECONNECT_DELAY_SECONDS = 3
WIFI_CONNECT_TIMEOUT_MS = 20000
WIFI_RETRY_DELAY_MS = 2000
LED_ON_DURATION_MS = 10000
LED_TIMER_INTERVAL_MS = 50

WIFI_STATUS_NAMES = {
    -3: "wrong password",
    -2: "access point not found",
    -1: "connection failed",
    0: "idle",
    1: "connecting",
    3: "connected",
    201: "access point not found",
    202: "authentication rejected",
    1001: "connecting",
}


sensor_1 = Pin(SENSOR_1_PIN, Pin.IN)
sensor_2 = Pin(SENSOR_2_PIN, Pin.IN)
led = Pin(LED_PIN, Pin.OUT)
led.off()


def validate_config():
    if not isinstance(SSID, str) or not SSID or SSID == "YOUR_WIFI_NAME":
        raise RuntimeError("SSID is not configured in esp_config.py")
    if (
        not isinstance(PASSWORD, str)
        or not PASSWORD
        or PASSWORD == "YOUR_WIFI_PASSWORD"
    ):
        raise RuntimeError("PASSWORD is not configured in esp_config.py")
    if not isinstance(HOST, str) or not HOST:
        raise RuntimeError("HOST is not configured in esp_config.py")
    if not isinstance(SEAT_ID, str) or not SEAT_ID:
        raise RuntimeError("SEAT_ID is not configured in esp_config.py")


def wifi_status_text(wifi):
    status = wifi.status()
    return "{} ({})".format(status, WIFI_STATUS_NAMES.get(status, "unknown"))


def sync_led(state):
    led.value(1 if state.led_on else 0)


async def sensor_loop(state, pending_events):
    next_read_at = time.ticks_add(time.ticks_ms(), SENSOR_INTERVAL_MS)

    while True:
        wait_ms = time.ticks_diff(next_read_at, time.ticks_ms())
        if wait_ms > 0:
            await asyncio.sleep_ms(wait_ms)

        sensor_1_occupied = sensor_1.value() != AVAILABLE_SENSOR_VALUE
        sensor_2_occupied = sensor_2.value() != AVAILABLE_SENSOR_VALUE
        led_was_on = state.led_on
        state.add_reading(sensor_1_occupied, sensor_2_occupied)
        sync_led(state)

        if led_was_on and not state.led_on:
            print("LED OFF because seat became occupied")
            pending_events.append(
                {
                    "type": "seat_led_state",
                    "seat_id": SEAT_ID,
                    "led_on": False,
                    "reason": "occupied",
                }
            )

        next_read_at = time.ticks_add(next_read_at, SENSOR_INTERVAL_MS)
        if time.ticks_diff(time.ticks_ms(), next_read_at) >= 0:
            next_read_at = time.ticks_add(time.ticks_ms(), SENSOR_INTERVAL_MS)


async def connect_wifi(wifi):
    attempt = 0

    while not wifi.isconnected():
        attempt += 1
        print("Wi-Fi attempt", attempt)

        try:
            wifi.active(True)
            wifi.disconnect()
        except OSError:
            pass

        await asyncio.sleep_ms(250)

        try:
            wifi.connect(SSID, PASSWORD)
        except OSError as error:
            print("Wi-Fi connect call failed:", error)
            await asyncio.sleep_ms(WIFI_RETRY_DELAY_MS)
            continue

        started_at = time.ticks_ms()
        while not wifi.isconnected() and time.ticks_diff(
            time.ticks_ms(), started_at
        ) < WIFI_CONNECT_TIMEOUT_MS:
            await asyncio.sleep_ms(250)

        if not wifi.isconnected():
            print("Wi-Fi attempt failed:", wifi_status_text(wifi))
            await asyncio.sleep_ms(WIFI_RETRY_DELAY_MS)

    print("Connected to Wi-Fi")
    print("Seat ESP IP:", wifi.ifconfig()[0])


async def led_timer_loop(state, pending_events):
    while True:
        if state.expire_led(time.ticks_ms(), time.ticks_diff):
            sync_led(state)
            print("LED OFF after 10 seconds")
            pending_events.append(
                {
                    "type": "seat_led_state",
                    "seat_id": SEAT_ID,
                    "led_on": False,
                    "reason": "timeout",
                }
            )
        await asyncio.sleep_ms(LED_TIMER_INTERVAL_MS)


async def send_message(writer, message, send_lock):
    async with send_lock:
        writer.write((json.dumps(message) + "\n").encode())
        await writer.drain()


async def event_sender_loop(writer, send_lock, pending_events):
    while True:
        if pending_events:
            message = pending_events[0]
            await send_message(writer, message, send_lock)
            pending_events.pop(0)
            continue
        await asyncio.sleep_ms(LED_TIMER_INTERVAL_MS)


def handle_server_message(state, message):
    message_type = message.get("type")
    request_id = message.get("request_id")

    if message_type == "get_status" and request_id is not None:
        return {
            "type": "seat_status",
            "request_id": request_id,
            "status": state.status,
            "led_on": state.led_on,
            "led_remaining_ms": state.led_remaining_ms(
                time.ticks_ms(),
                time.ticks_diff,
            ),
        }

    if message_type == "set_led" and request_id is not None:
        value = message.get("value")
        deadline_ms = None
        if value == 1:
            deadline_ms = time.ticks_add(
                time.ticks_ms(),
                LED_ON_DURATION_MS,
            )
        result = state.set_led(value, deadline_ms)
        sync_led(state)
        if result == LED_ACTIVATED:
            print("LED ON for 10 seconds")
        elif result == LED_ALREADY_ACTIVE:
            print("LED already active; timer unchanged")
        elif result == LED_DEACTIVATED:
            print("LED OFF")
        else:
            print("LED command rejected:", result)
        return {
            "type": "set_led_result",
            "request_id": request_id,
            "accepted": result in (LED_ACTIVATED, LED_DEACTIVATED),
            "result": result,
            "led_on": state.led_on,
            "led_remaining_ms": state.led_remaining_ms(
                time.ticks_ms(),
                time.ticks_diff,
            ),
        }

    print("Unknown or invalid command:", message)
    return {
        "type": "error",
        "request_id": request_id,
        "error": "invalid_command",
    }


async def close_writer(writer):
    if writer is None:
        return

    try:
        writer.close()
        if hasattr(writer, "wait_closed"):
            await writer.wait_closed()
    except OSError:
        pass


async def run_connection(state, pending_events):
    print("Connecting to server {}:{}...".format(HOST, PORT))
    reader, writer = await asyncio.open_connection(HOST, PORT)
    print("Connected to server as", SEAT_ID)
    send_lock = asyncio.Lock()
    event_sender = None

    try:
        await send_message(
            writer,
            {
                "type": "seat_register",
                "seat_id": SEAT_ID,
            },
            send_lock,
        )
        print("Seat registered as", SEAT_ID)
        event_sender = asyncio.create_task(
            event_sender_loop(writer, send_lock, pending_events)
        )

        while True:
            line = await reader.readline()
            if not line:
                raise RuntimeError("Server disconnected")

            try:
                message = json.loads(line)
            except ValueError as error:
                print("Invalid server message:", error)
                continue

            response = handle_server_message(state, message)
            await send_message(writer, response, send_lock)
    finally:
        if event_sender is not None:
            event_sender.cancel()
        await close_writer(writer)


async def communication_loop(state, pending_events):
    wifi = network.WLAN(network.STA_IF)

    while True:
        try:
            if not wifi.isconnected():
                await connect_wifi(wifi)
            await run_connection(state, pending_events)
        except Exception as error:
            print("Connection error:", error)
            state.set_led(0)
            sync_led(state)
            await asyncio.sleep(RECONNECT_DELAY_SECONDS)


async def main_async():
    validate_config()
    state = SeatState(WINDOW_SIZE)
    pending_events = []

    print("Starting seat controller", SEAT_ID)
    print(
        "Sensors GPIO{} and GPIO{}, LED GPIO{}".format(
            SENSOR_1_PIN, SENSOR_2_PIN, LED_PIN
        )
    )

    asyncio.create_task(sensor_loop(state, pending_events))
    asyncio.create_task(led_timer_loop(state, pending_events))
    await communication_loop(state, pending_events)


def main():
    try:
        asyncio.run(main_async())
    finally:
        asyncio.new_event_loop()


if __name__ == "__main__":
    main()

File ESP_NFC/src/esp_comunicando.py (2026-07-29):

# ESP32-C3 SuperMini + PN532 I2C + TCP/IP communication.
#
# Wiring:
# - PN532 SDA -> GPIO8
# - PN532 SCL -> GPIO9
# - buzzer +  -> GPIO4
# - buzzer -  -> GND

import json
import machine
import network
import socket
import time
from micropython import const

try:
    from esp_config import HOST, PASSWORD, SSID
except ImportError:
    raise RuntimeError(
        "Missing esp_config.py. Copy esp_config.example.py and configure Wi-Fi/PC."
    )


# ==========================
# Wi-Fi / PC configuration
# ==========================

# Port used by servidor/src/pc_server.py
PORT = 5000


# ==========================
# NFC configuration
# ==========================

I2C_ID = 0
I2C_SDA_PIN = 8
I2C_SCL_PIN = 9
I2C_FREQ = 100000

PN532_I2C_ADDRESS = const(0x24)

BUZZER_PIN = 4
BUZZER_FREQ = 2200
BUZZER_DUTY_U16 = 49152

# Coloque aqui os UUIDs/UIDs autorizados, no mesmo formato impresso no terminal.
# O primeiro UID da lista envia {"nfc_1": 1}, o segundo envia {"nfc_2": 1}, etc.
NFC_UUIDS = [
    "d3:8e:18:06",
]

READ_COOLDOWN_MS = 1500

_PREAMBLE = const(0x00)
_STARTCODE1 = const(0x00)
_STARTCODE2 = const(0xFF)
_POSTAMBLE = const(0x00)

_HOSTTOPN532 = const(0xD4)
_PN532TOHOST = const(0xD5)

_COMMAND_GETFIRMWAREVERSION = const(0x02)
_COMMAND_SAMCONFIGURATION = const(0x14)
_COMMAND_RFCONFIGURATION = const(0x32)
_COMMAND_INLISTPASSIVETARGET = const(0x4A)

_MIFARE_ISO14443A = const(0x00)
_I2C_READY = const(0x01)

_ACK = b"\x00\x00\xFF\x00\xFF\x00"
PN532_ACK_TIMEOUT_MS = 30
PN532_SEARCH_TIMEOUT_MS = 180
POLL_INTERVAL_MS = 50
CONSECUTIVE_READER_ERRORS = 5
CARD_ABSENCE_POLLS = 2
HEARTBEAT_INTERVAL_MS = 2000


class BusyError(Exception):
    pass


class PN532FrameWarning(Exception):
    pass


class PN532ResponseTimeout(RuntimeError):
    pass


class PN532AckTimeout(PN532ResponseTimeout):
    pass


class PN532:
    def __init__(self, *, debug=False):
        self.debug = debug
        self._wakeup()

    def _read_data(self, count):
        raise NotImplementedError

    def _write_data(self, framebytes):
        raise NotImplementedError

    def _wait_ready(self, timeout):
        raise NotImplementedError

    def _wakeup(self):
        raise NotImplementedError

    def _write_frame(self, data):
        length = len(data)
        frame = bytearray(length + 8)
        frame[0] = _PREAMBLE
        frame[1] = _STARTCODE1
        frame[2] = _STARTCODE2
        checksum = sum(frame[0:3])
        frame[3] = length & 0xFF
        frame[4] = (~length + 1) & 0xFF
        frame[5:-2] = data
        checksum += sum(data)
        frame[-2] = ~checksum & 0xFF
        frame[-1] = _POSTAMBLE

        if self.debug:
            print("Write frame:", [hex(byte) for byte in frame])
        self._write_data(bytes(frame))

    def _read_frame(self, length):
        response = self._read_data(length + 8)
        if self.debug:
            print("Read frame:", [hex(byte) for byte in response])

        offset = 0
        while response[offset] == 0x00:
            offset += 1
            if offset >= len(response):
                raise PN532FrameWarning("Response frame preamble does not contain 0x00FF")

        if response[offset] != 0xFF:
            raise PN532FrameWarning("Response frame preamble does not contain 0x00FF")

        offset += 1
        if offset >= len(response):
            raise PN532FrameWarning("Response contains no data")

        frame_len = response[offset]
        if (frame_len + response[offset + 1]) & 0xFF != 0:
            raise PN532FrameWarning("Response length checksum did not match length")

        checksum = sum(response[offset + 2 : offset + 2 + frame_len + 1]) & 0xFF
        if checksum != 0:
            raise PN532FrameWarning("Response checksum did not match expected value")

        return response[offset + 2 : offset + 2 + frame_len]

    def call_function(
        self,
        command,
        response_length=0,
        params=None,
        ack_timeout_ms=PN532_ACK_TIMEOUT_MS,
        response_timeout_ms=500,
    ):
        if params is None:
            params = []

        data = bytearray(2 + len(params))
        data[0] = _HOSTTOPN532
        data[1] = command & 0xFF
        for index, value in enumerate(params):
            data[2 + index] = value

        self._write_frame(data)
        if not self._wait_ready(ack_timeout_ms):
            raise PN532AckTimeout("timeout waiting for ACK")

        if self._read_data(len(_ACK)) != _ACK:
            raise RuntimeError("Did not receive expected ACK from PN532")

        if not self._wait_ready(response_timeout_ms):
            raise PN532ResponseTimeout("timeout waiting for response")

        response = self._read_frame(response_length + 2)
        if (
            len(response) < 2
            or response[0] != _PN532TOHOST
            or response[1] != command + 1
        ):
            raise RuntimeError("Received unexpected command response")

        return response[2:]

    def get_firmware_version(self):
        if self.debug:
            print("Get firmware version")

        response = self.call_function(
            _COMMAND_GETFIRMWAREVERSION,
            4,
            response_timeout_ms=500,
        )

        if self.debug:
            print("Get firmware version response:", tuple(response))
        return tuple(response)

    def SAM_configuration(self):
        self.call_function(
            _COMMAND_SAMCONFIGURATION,
            params=[0x01, 0x14, 0x01],
            response_timeout_ms=500,
        )
        # Use one passive activation attempt per poll. This prevents an old
        # search response from being consumed by the following command.
        self.call_function(
            _COMMAND_RFCONFIGURATION,
            params=[0x05, 0xFF, 0x01, 0x00],
            response_timeout_ms=500,
        )

    def read_passive_target(self, card_baud=_MIFARE_ISO14443A):
        try:
            response = self.call_function(
                _COMMAND_INLISTPASSIVETARGET,
                params=[0x01, card_baud],
                response_length=19,
                response_timeout_ms=PN532_SEARCH_TIMEOUT_MS,
            )
        except PN532ResponseTimeout as error:
            if isinstance(error, PN532AckTimeout):
                raise
            return None

        if not response or response[0] == 0:
            return None

        if response[0] != 1 or len(response) < 6:
            raise RuntimeError("Invalid PN532 target response")

        uid_length = response[5]
        if uid_length > 7 or len(response) < 6 + uid_length:
            raise RuntimeError("Found card with unexpectedly long UID")

        return response[6 : 6 + uid_length]
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

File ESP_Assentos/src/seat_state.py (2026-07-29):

STATUS_OCCUPIED = "ocupado"
STATUS_AVAILABLE = "disponível"

LED_ACTIVATED = "activated"
LED_ALREADY_ACTIVE = "already_active"
LED_OCCUPIED = "occupied"
LED_INVALID_VALUE = "invalid_value"
LED_DEACTIVATED = "deactivated"


class SeatState:
    def __init__(self, window_size=10):
        if window_size <= 0:
            raise ValueError("window_size must be positive")

        self.window_size = window_size
        self.sensor_1_window = [False] * window_size
        self.sensor_2_window = [False] * window_size
        self.next_index = 0
        self.sample_count = 0
        self.occupied_readings = 0
        self.led_on = False
        self.led_deadline_ms = None

    @property
    def status(self):
        if self.sample_count < self.window_size or self.occupied_readings > 0:
            return STATUS_OCCUPIED
        return STATUS_AVAILABLE

    @property
    def is_available(self):
        return self.status == STATUS_AVAILABLE

    def add_reading(self, sensor_1_occupied, sensor_2_occupied):
        sensor_1_occupied = bool(sensor_1_occupied)
        sensor_2_occupied = bool(sensor_2_occupied)

        if self.sample_count == self.window_size:
            self.occupied_readings -= int(
                self.sensor_1_window[self.next_index]
            )
            self.occupied_readings -= int(
                self.sensor_2_window[self.next_index]
            )
        else:
            self.sample_count += 1

        self.sensor_1_window[self.next_index] = sensor_1_occupied
        self.sensor_2_window[self.next_index] = sensor_2_occupied
        self.occupied_readings += int(sensor_1_occupied)
        self.occupied_readings += int(sensor_2_occupied)
        self.next_index = (self.next_index + 1) % self.window_size

        if (sensor_1_occupied or sensor_2_occupied) and self.led_on:
            self.set_led(0)

        return self.status

    def set_led(self, value, deadline_ms=None):
        if value == 0:
            self.led_on = False
            self.led_deadline_ms = None
            return LED_DEACTIVATED

        if value != 1:
            return LED_INVALID_VALUE

        if self.led_on:
            return LED_ALREADY_ACTIVE

        if not self.is_available:
            return LED_OCCUPIED

        self.led_on = True
        self.led_deadline_ms = deadline_ms
        return LED_ACTIVATED

    def led_remaining_ms(self, now_ms, ticks_diff):
        if not self.led_on or self.led_deadline_ms is None:
            return 0
        return max(0, ticks_diff(self.led_deadline_ms, now_ms))

    def expire_led(self, now_ms, ticks_diff):
        if not self.led_on or self.led_deadline_ms is None:
            return False
        if ticks_diff(now_ms, self.led_deadline_ms) < 0:
            return False

        self.led_on = False
        self.led_deadline_ms = None
        return True

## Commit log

2026-07-08 Add project reproduction and structural components
    Document the structural components and prototypes for the project, including details for the NFC reading module, intermediary PC, and seating modules.
2026-07-08 Refactor NFC buzzer firmware
    [pn532_i2c.py]
2026-07-14 Add touch sensor script for TTP223B
    Implement touch sensor functionality with LED control.
2026-07-22 Ajusta página de implementação
2026-07-22 Adiciona as specs que o wesley fez como README do modulo
2026-07-24 update new logic for sensors
2026-07-24 Update README to include resistor for LED
    Add information about resistor for LED in README.
2026-07-25 ajusta pastas do repositório
    [ModuloToque.fzz, NFCBuzzerProject.fzz]
2026-07-28 CHECK RAFA
    Added detailed project documentation including structure, responsibilities of each ESP32, communication flow, libraries used, and future implementations.
2026-07-28 tinha quebrado
    Removed message flow diagram from README.
2026-07-29 Stabilize NFC and seat LED protocol
    [esp_comunicando.py, seat_state.py, sensor_v1.py]
2026-07-29 turn off seat LED on occupancy
2026-07-29 update README to match current behavior
2026-07-29 Update README
    Add detailed message flow and software resource descriptions.
2026-07-29 landing page
